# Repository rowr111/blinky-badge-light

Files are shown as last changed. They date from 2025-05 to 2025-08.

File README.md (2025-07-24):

# Blinky Badge "light"!
Hello!  Welcome to the github repo for Blinky Badge "light".

## What is this thing?
 - Blinky Badge "light" is a lighting badge with unique patterns and sound reactivity! 
 - It's meant to be worn at festivals or whenever you'd like to light your person in a fun way.  Safety!
 - Heart shaped!

## Why is it named Blinky Badge "light"?
### This project shares similar features with two projects:
   -  [bunnie's BM blinky badge of 2017 and 2020](https://github.com/bunnie/chibios-xz/tree/bm20)
   -  [the cubegarden art project](https://github.com/rowr111/cubegarden)

### So, about the name?

- Although this project was written from scratch, has some different features, and uses a different microcontroller etc from the original badge, it shares the fundamental shared goal of the original - to light up the night in a fun and personal way!
- I also re-use the pattern generation concepts from the original badge in some of the patterns, so visually there are also some similarities.
- This badge does not share the radio communication features of the original, nor does it have a screen/ui - thus it's called blinky badge "light".  (Also, it makes.. light. get it? :D)
   
## Features
### Patterns:
 - three unique patterns generated on initial startup for each badge (not sound reactive)
 - two sound reactive patterns with a base same as ^
    - flashes the whole badge
    - fills up the badge from the bottom
 - one 'safety' pattern
    - not in the normal pattern list
    - forced when battery level is very low
- future pattern ideas:
    - sound reactive pattern whose color indicates dB level?  tbd..

### Capacitive Touch Buttons:
1. iterate through unique patterns (wraps around when gets to the end)
2. change brightness level (wraps around after brightest)
3. replace current pattern with new unique pattern
    - for sound reactive patterns changes the base pattern, not sound reactivity
    - small flash on pattern change for visual indicator of change
4. off (hold)
5. check battery level
6. ? (mystery spot. does nothing for now. use it to add a feature!)

### Power Button (physical button):
 - press to turn badge on

### Power Indicator LED (small, green):
 - on during charging

## Physical Structure/Components

The badge is a heart shaped PCB with LEDs outlining the heart.  The LEDs are covered by the case for protection and some light diffusion, but the center front of the PCB is exposed for easy access of the buttons.

The form is similar to the original blinky badge, but there are differences:
 - the original has 36 LEDs, this badge has 24.
 - the original has a screen and antenna, this badge does not.
 - the original has 8 capacitive touch buttons, this badge has 3 big and 3 small ones.
 - this badge uses a user-supplied, removeable battery.

### Structural Components (WIP!)
 - PCB with these main components:
   - ESP32 microcontroller
   - microphone
   - 24 WS2812B LEDs
   - USB-C port for:
     - charging batteries
     - programming the microcontroller
   - 6 capacitive touch buttons
     - change pattern
     - change brightness
     - replace current pattern with new unique pattern
     - off
     - battery check
     - ? mystery spot
   - power button for On
   - small led for lower battery charge/currently charging indicator
   - battery holder attached to the back
      - requires one 18650 lithium-ion rechargeable battery
 - Case:
   - heart shaped ring on the front, same as the original blinky badge
   - back fully covers the back of the PCB as well as protects the battery holder
   - will have various points for attaching/hanging the badge

## How to write code for the badge!
 - Visual Studio Code
 - add the Espressif IDF extension
 - set up the extension
   - configure ESP-IDF extension, I recommend Express mode:  
     - install idf release version 5.5 (can prob use later versions too, but use at least this version)
     - no other configuration needed!
 - install CP210x Universal Windows Driver (or appropriate driver for your OS) from [CP2102N USB to UART Bridge Controller](https://www.silabs.com/software-and-tools/usb-to-uart-bridge-vcp-drivers?tab=downloads)
 - plug in badge to computer using USB-C cable that *supports data transmission*
 - open the blinky-badge-light/blinky-badge-light folder in VSCode
 - update code on badge using ESP-IDF:
   - FIRST TIME: 
     - go to ESP-IDF: EXPLORER (list of commands) from  icon in VS Code's plugin icon menu
     - select current ESP-IDF version (5.5 that you just installed)
     - select flash method - UART
     - 'Select Port to Use (COM, tty, usbserial)'
       - hold down 'ON' button on badge (or just make sure the badge is on)
       - click 'Select Port to Use (COM, tty, usbserial)'
       - pick the port that matches your badge (check in device manager if you're not sure)
     - 'Select Monitor Port to Use (COM, tty, usbserial)'
       - repeat ^ process and pick the same port
     - Full Clean
     - Build Project
     - Flash Device
       - ON button must be held down while flash happens
     - after flash is complete, release ON, then press and hold ON to start the badge
     - once badge has started, you can use 'Monitor Device' to see the serial monitor.
   - BUILDING AFTER THIS FIRST SETUP BUILD:
     - just do build/flash steps!
     - if you have problems:
       - check if the com port changed for some reason and reset them
       - full clean before rebuilding
 - Now that you know how to update the code, add your own fun stuff!
 - Code Ideas:
   - something using the antenna? 
   - cool new lighting patterns?
   - use the ? mystery spot capacitive touch pad to do something cool?

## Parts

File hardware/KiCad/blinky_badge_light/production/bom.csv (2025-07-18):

Designator | Footprint | Quantity | Value | LCSC Part #
BT1 | BatteryHolder_Keystone_1042_1x18650 | 1 | 3.7V - 4.2V | C2988620
C1, C10, C11, C12, C13, C14, C15, C16, C17, C18, C19, C2, C20, C21, C22, C23, C24, C26, C29, C3, C31, C36, C37, C38, C4, C41, C5, C6, C7, C8, C9 | 0402 | 31 | 100nF | C1525
C25, C34, C35, C40 | 0603 | 4 | 1µF | C15849
C27, C28, C39 | 0603 | 3 | 22µF | C59461
C30 | 0603 | 1 | 4.7µF | C19666
C32, C33 | 0603 | 2 | 10µF | C96446
D1, D10, D11, D12, D13, D14, D15, D16, D17, D18, D19, D2, D20, D21, D22, D23, D24, D3, D4, D5, D6, D7, D8, D9 | LED_WS2812B_PLCC4_5.0x5.0mm_P3.2mm | 24 | WS2812B | C2761795
D25 | 0805 | 1 | LED | C2297
D26 | D_SOD-323F | 1 | D_Schottky | C50704
D27 | SOT-143-4_L2.9-W1.3-P1.92-LS2.4-BL | 1 | SP0503BAHT | C3040626
D28 | D_SOD-123 | 1 | ESD Diode | C5380694
L1 | IND-SMD_L4.5-W4.1_IHLP | 1 | 4.7µH | C22463808
MK1 | InvenSense_ICS-43434-6_3.5x2.65mm | 1 | ICS-43434 | C5656610
Q1, Q3 | SOT-23-3_L2.9-W1.3-P1.90-LS2.4-BR | 2 | N-Channel MOSFET | C20917
Q2, Q4 | SOT-23 | 2 | Q_PMOS_GSD | C88052
R1 | 0603 | 1 | 100Ω | C22775
R10 | 0603 | 1 | 1kΩ | C21190
R11, R12, R13, R18, R19, R2, R20, R8 | 0603 | 8 | 10kΩ | C25804
R14 | 0603 | 1 | 3kΩ | C4211
R15, R9 | 0603 | 2 | 100kΩ | C25803
R16 | 0603 | 1 | 22.1kΩ | C25961
R17 | 0603 | 1 | 47.5kΩ | C23061
R3 | 0603 | 1 | 1Ω | C22936
R4 | 0603 | 1 | 2kΩ | C22975
R5 | 0603 | 1 | 5.1kΩ | C23186
R7 | 0603 | 1 | 73.2kΩ | C163420
SW1 | SW-SMD_4P-L5.1-W5.1-P3.70-LS6.5-TL_H1.5 | 1 | TS-1187A-B-A-B | C318884
U1 | ESP32-S3-WROOM-1 | 1 | ESP32-S3-WROOM-1 | C2913198
U2 | SOP8-PP_TPW | 1 | TP4056 | C16581
U3 | SOT-23-5 | 1 | AP2112K-3.3 | C51118
U4 | SOT-23-6 | 1 | MT3608 | C84817
U5 | QFN-24-1EP_4x4mm_P0.5mm_EP2.6x2.6mm | 1 | CP2102N-Axx-xQFN24 | C969151
U6 | SOT-23-6 | 1 | SN74LVC1T45DBV | C7843
USBC1 | USB-C_SMD-TYPE-C-31-M-12 | 1 | ~ | C165948

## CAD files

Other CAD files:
3d models/blinky_badge_light_case.f3d

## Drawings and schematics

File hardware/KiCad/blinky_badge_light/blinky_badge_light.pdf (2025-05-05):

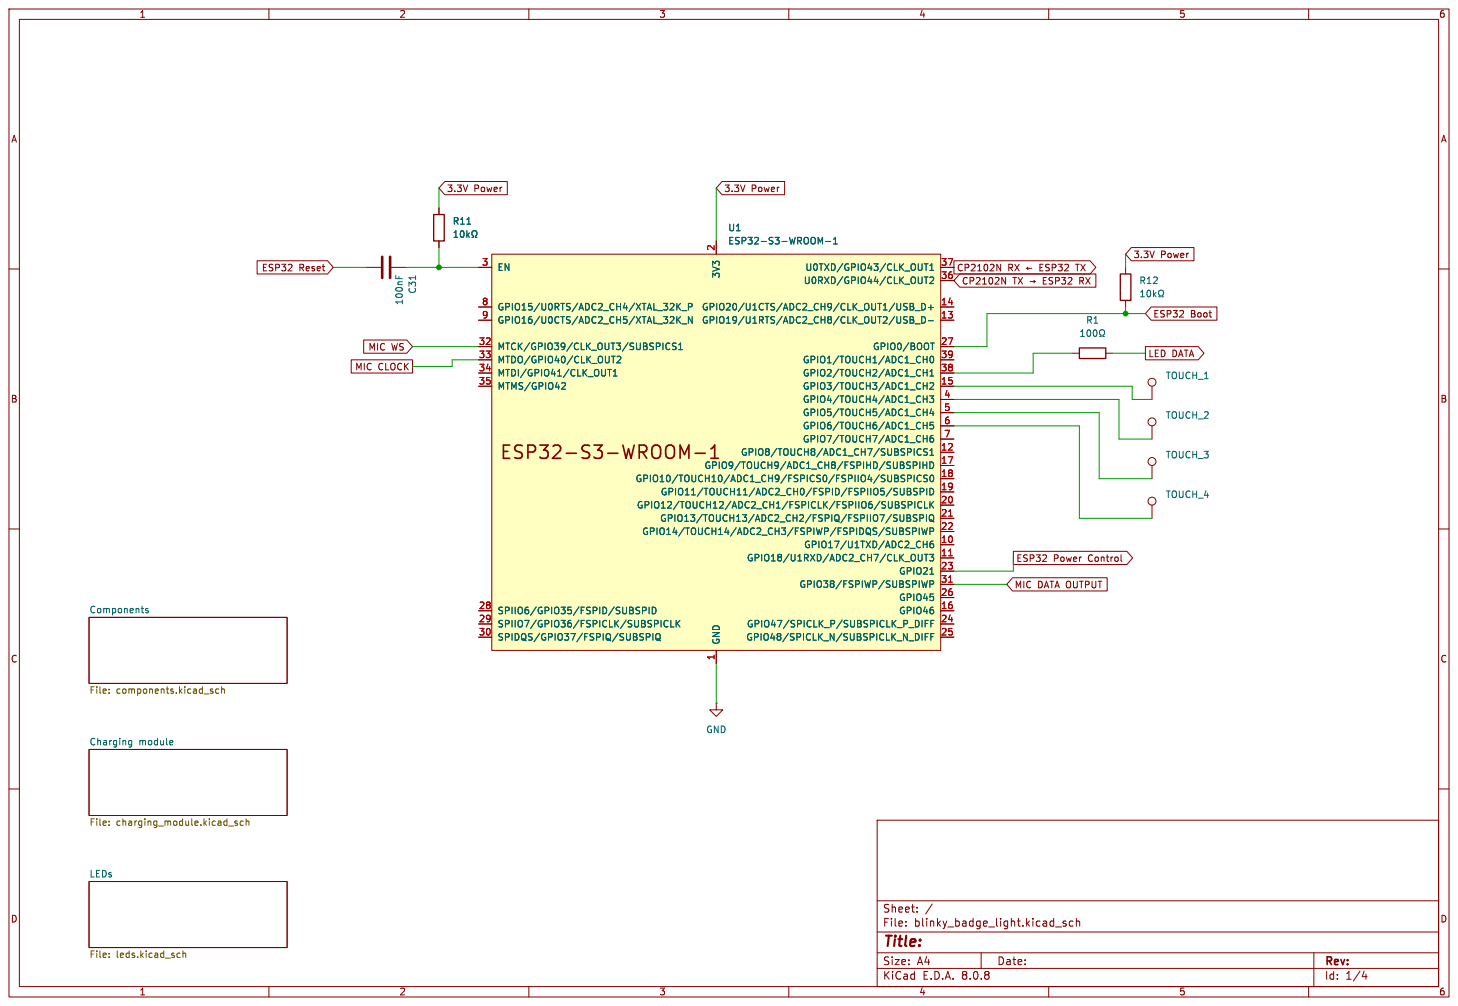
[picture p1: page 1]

2 GPIO12/TOUCH12/ADC2_CH1/FSPICLK/FSPIIO6/SUBSPICLK 20 GPIO13/TOUCH13/ADC2_CH2/FSPIQ/FSPIIO7/SUBSPIQ 21 GPIO14/TOUCH14/ADC2_CH3/FSPIWP/FSPIDQS/SUBSPIWP 22 GPIO21 23 GPIO47/SPICLK_P/SUBSPICLK_P_DIFF 24 GPIO48/SPICLK_N/SUBSPICLK_N_DIFF 25 GPIO45 26 GPIO0/BOOT 27 SPIIO6/GPIO35/FSPID/SUBSPID 28 SPIIO7/GPIO36/FSPICLK/SUBSPICLK 29 EN 3 SPIDQS/GPIO37/FSPIQ/SUBSPIQ 30 GPIO38/FSPIWP/SUBSPIWP 31 MTCK/GPIO39/CLK_OUT3/SUBSPICS1 32 MTDO/GPIO40/CLK_OUT2 33 MTDI/GPIO41/CLK_OUT1 34 MTMS/GPIO42 35 U0RXD/GPIO44/CLK_OUT2 36 U0TXD/GPIO43/CLK_OUT1 37 GPIO2/TOUCH2/ADC1_CH1 38 GPIO1/TOUCH1/ADC1_CH0 39 GPIO4/TOUCH4/ADC1_CH3 4 GPIO5/TOUCH5/ADC1_CH4 5 GPIO6/TOUCH6/ADC1_CH5 6 GPIO7/TOUCH7/ADC1_CH6 7 GPIO15/U0RTS/ADC2_CH4/XTAL_32K_P 8 GPIO16/U0CTS/ADC2_CH5/XTAL_32K_N 9 U1ESP32-S3-WROOM-1 R11

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

1 GPIO17/U1TXD/ADC2_CH6 10 GPIO18/U1RXD/ADC2_CH7/CLK_OUT3 11 GPIO8/TOUCH8/ADC1_CH7/SUBSPICS1 12 GPIO19/U1RTS/ADC2_CH8/CLK_OUT2/USB_D- 13 GPIO20/U1CTS/ADC2_CH9/CLK_OUT1/USB_D+ 14 GPIO3/TOUCH3/ADC1_CH2 15 GPIO46 16 GPIO9/TOUCH9/ADC1_CH8/FSPIHD/SUBSPIHD 17 GPIO10/TOUCH10/ADC1_CH9/FSPICS0/FSPIIO4/SUBSPICS0 18 GPIO11/TOUCH11/ADC2_CH0/FSPID/FSPIIO5/SUBSPID 19 3V3

Id: 1/4 Title: File: blinky_badge_light.kicad_sch Sheet: / LEDs File: leds.kicad_sch Components File: components.kicad_sch

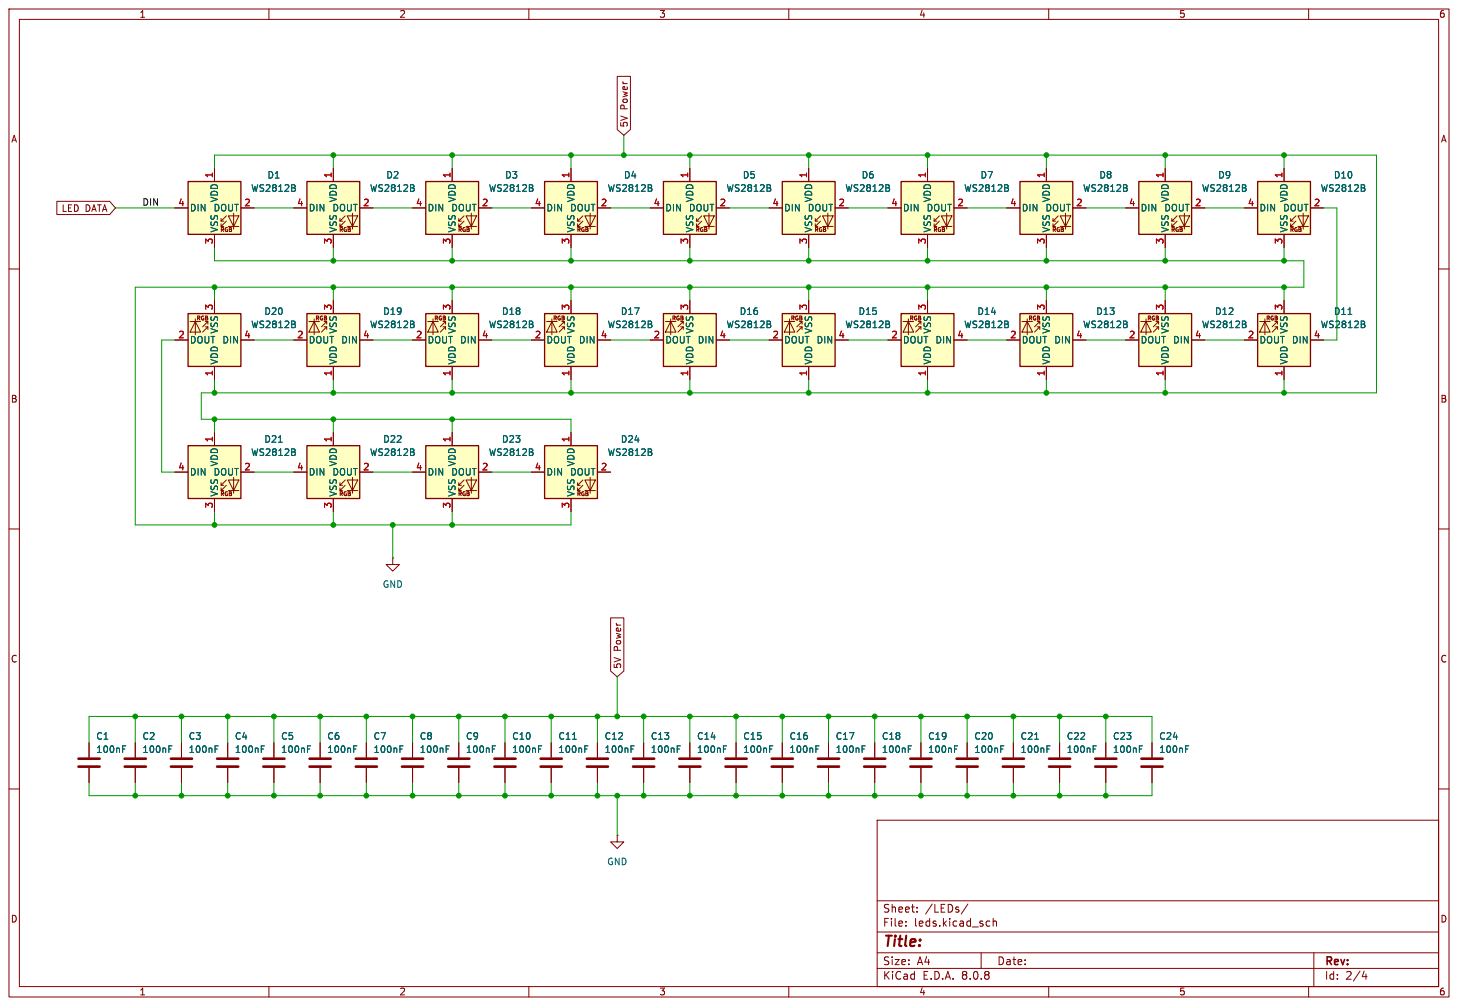
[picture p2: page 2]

Id: 2/4 Title: File: leds.kicad_sch Sheet: /LEDs/ C4

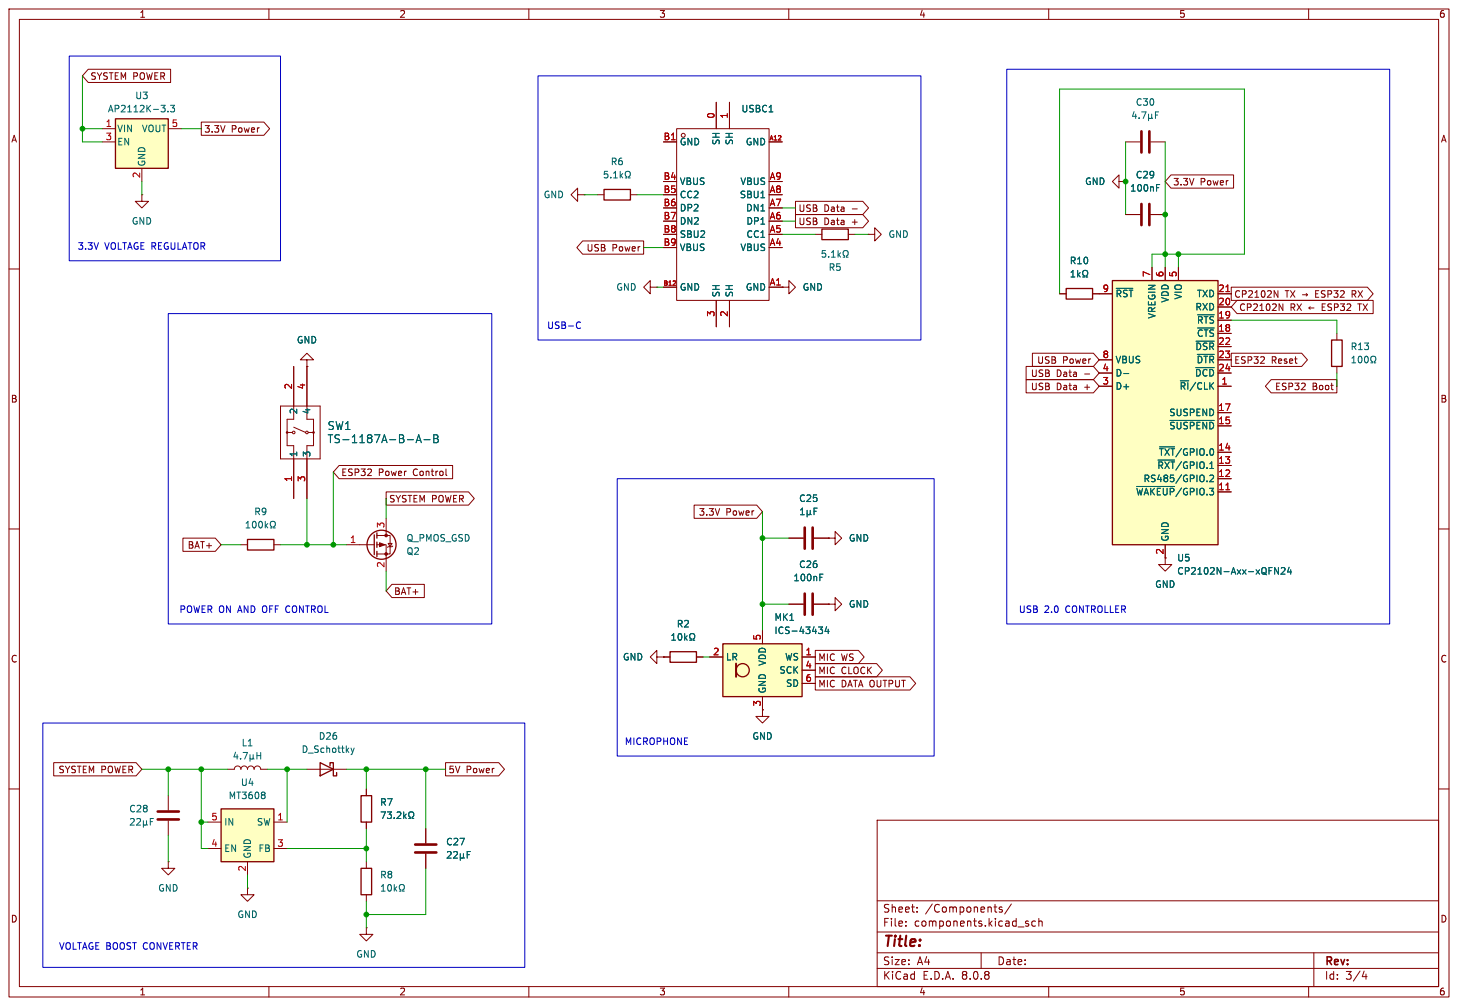
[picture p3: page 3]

2 EN 3 VOUT 5 U3 AP2112K-3.3 ~{RI}/CLK1 ~{WAKEUP}/GPIO.311 RS485/GPIO.2 12 ~{RXT}/GPIO.113 ~{TXT}/GPIO.014 ~{SUSPEND}15 SUSPEND 17 ~{CTS} 18 ~{RTS} 19 GND

3 GND A1 GND A12 VBUS A4 CC1 A5 DP1 A6 DN1 A7 SBU1 A8 VBUS A9 GND B1 GND B12 VBUS B4 CC2 B5 DP2 B6 DN2 B7 SBU2 B8 VBUS B9 USBC1 VIN 1 GND

þÿ5.1k© GND GND SH

3 GND A1 GND A12 VBUS A4 CC1 A5 DP1 A6 DN1 A7 SBU1 A8 VBUS A9 GND B1 GND B12 VBUS B4 CC2 B5 DP2 B6 DN2 B7 SBU2 B8 VBUS B9 MK1

7 VBUS 8 ~{RST} 9 U5 CP2102N-Axx-xQFN24 GND

2 RXD 20 TXD 21 ~{DSR} 22 ~{DTR} 23 ~{DCD} 24 D+ 3 D- 4 VIO

Id: 3/4 Title: File: components.kicad_sch Sheet: /Components/ C26

POWER ON AND OFF CONTROL

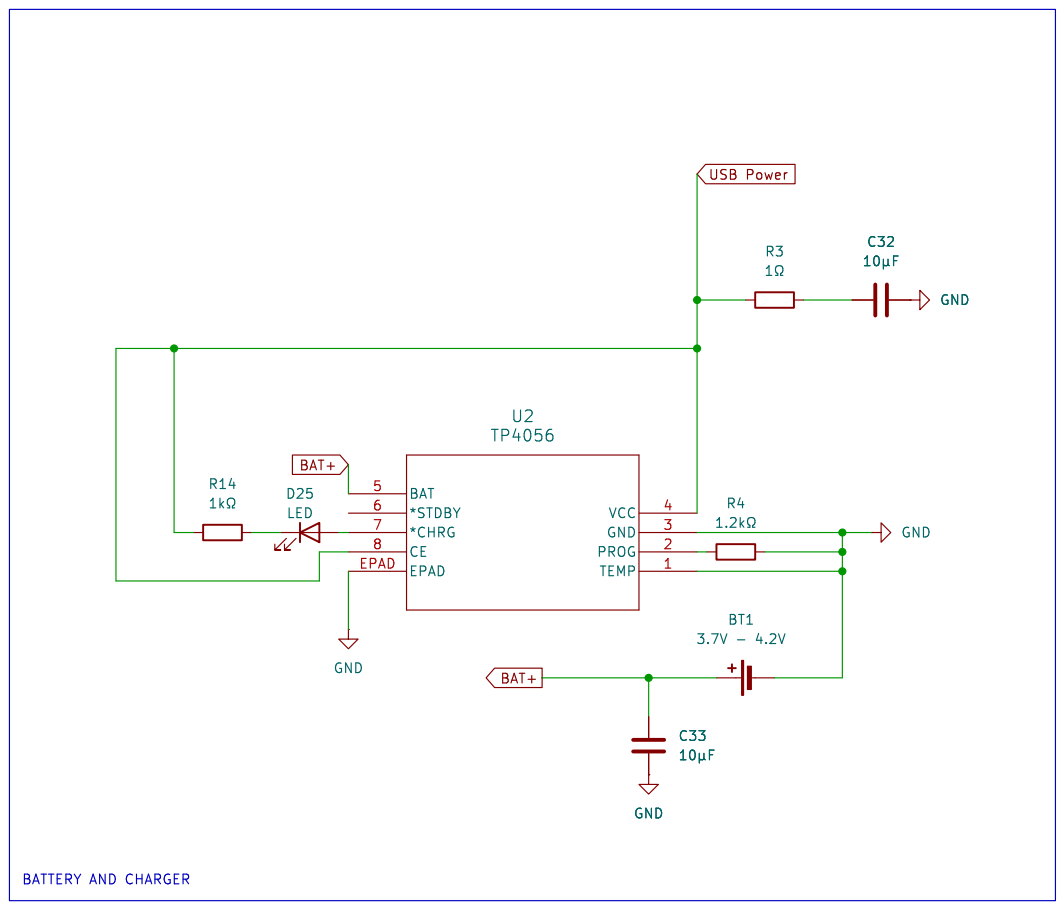
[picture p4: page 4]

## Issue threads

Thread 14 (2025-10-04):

sometimes on low battery captouch buttons don't seem to work to turn off the badge

rowr111, 2025-10-04:
maybe this is unnecessary to fix if I switch to using the same push button button for off/on.  I couldn't repro it here no matter what I tried but I did see it in the field.  could try recalibrating captouch buttons when reach low voltage.

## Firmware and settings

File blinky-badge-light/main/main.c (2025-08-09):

#include "esp_log.h"
#include "esp_timer.h"
#include "freertos/FreeRTOS.h"
#include "freertos/task.h"
#include "nvs_flash.h"
#include "esp_system.h"

#include "battery_monitor.h"
#include "battery_level_pattern.h"
#include "led_control.h"
#include "touch_input.h"
#include "storage.h"
#include "genes.h"
#include "pins.h"
#include "microphone.h"
#include "now.h"
#include "testing_routine.h"

void app_main() {
    esp_reset_reason_t reason = esp_reset_reason();
    ESP_LOGI("MAIN", "Reset reason: %s", reset_reason_str(reason));

    // Initialize NVS
    esp_err_t ret = nvs_flash_init();
    if (ret != ESP_OK) {
        ESP_ERROR_CHECK(nvs_flash_erase());
        ret = nvs_flash_init();
    }
    ESP_ERROR_CHECK(ret);

    // Load or generate genomes
    load_genomes_from_storage();
    // Initialize components
    init_leds();
    init_touch();
    init_microphone();
    now_init();
    init_storage();
    init_battery_monitor();

    load_settings(&settings);
    set_pattern(settings.pattern_id);
    set_brightness(settings.brightness);

    ESP_LOGI("MAIN", "System initialized. Starting tasks...");

    // Create tasks
    xTaskCreatePinnedToCore(lighting_task, "Lighting Task", 4096, NULL, 5, NULL, 1);
    xTaskCreatePinnedToCore(battery_monitor_task, "Battery Monitor Task", 4096, NULL, 5, NULL, 0);
    xTaskCreatePinnedToCore(microphone_task, "Microphone Task", 4096, NULL, 5, NULL, 0);
    xTaskCreatePinnedToCore(touch_task, "Touch Task", 4096, NULL, 5, NULL, 0);
}

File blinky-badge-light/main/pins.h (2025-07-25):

#ifndef PINS_H
#define PINS_H

#include <driver/gpio.h>

// LED pins
#define LED_PIN GPIO_NUM_2 // GPIO pin for LED data
#define LED_COUNT 24 // Number of LEDs

// Battery monitoring pins
#define ADC_CHANNEL ADC_CHANNEL_8   // GPIO9 on ADC1
#define ADC_GPIO    GPIO_NUM_17
#define BATTERY_MONITOR_ENABLE_PIN GPIO_NUM_46 // GPIO46 controls battery monitor transistor

// Power pins
#define MOSFET_GATE_PIN GPIO_NUM_21
#define BUTTON_PIN 27 // Power button

// Microphone pins
#define I2S_SCK_PIN GPIO_NUM_40  // Clock Pin (BCLK), pin 33
#define I2S_WS_PIN  GPIO_NUM_39  // Word Select (LRCLK), pin 32
#define I2S_DI_PIN  GPIO_NUM_38  // Data In (DOUT), pin 31

#endif // PINS_H

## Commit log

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2024-12-31 fixing the touch input
    [main.c]
2025-01-01 generate new genome on long press of button 2, clean up press detection code
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2025-01-02 safety dance! we can dance if we wannuuuu... (even when power is critically low lol) - adding safety pattern.
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2025-02-09 first pass at hardware schematic
    [blinky_badge_light.kicad_pcb, blinky_badge_light.kicad_sch, charging_module.kicad_sch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]
2025-05-05 updates to hardware schematic
    [blinky_badge_light.kicad_pcb, blinky_badge_light.kicad_sch, charging_module.kicad_sch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]
2025-05-07 hardware updates, gitignore to ignore backups
    [blinky_badge_light.kicad_pcb, blinky_badge_light.kicad_sch]
2025-05-09 stuff from today
    [blinky_badge_light.kicad_pcb, blinky_badge_light.kicad_sch, charging_module.kicad_sch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]
2025-05-09 small changes from today
    [blinky_badge_light.kicad_pcb]
2025-05-09 changing led locations
    [blinky_badge_light.kicad_pcb]
2025-05-10 placing items on the board
    [blinky_badge_light.kicad_pcb, components.kicad_sch, leds.kicad_sch]
2025-05-12 fix some stuff with the footprints, rearrange some things
    [blinky_badge_light.kicad_pcb, blinky_badge_light.kicad_sch, components.kicad_sch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]
2025-05-13 pad 4 is now stop sign shaped since its the off button
    [blinky_badge_light.kicad_pcb, blinky_badge_light.kicad_sch]
2025-05-16 add exclusion zone for pads/screw holes for fill area
    [blinky_badge_light.kicad_pcb]
2025-05-17 some initial slight mods
    - improved USB signal layout
    - reviewed boost regulator
    - improved 3.3V power layout
    still need to have a look at the overall USB power routing
    [blinky_badge_light.kicad_pcb]
2025-05-17 rotate battery, charger IC
    [blinky_badge_light.kicad_pcb]
2025-05-18 clean up labels on the back
    [blinky_badge_light.kicad_pcb, blinky_badge_light.kicad_sch]
2025-05-19 update with routing
    [blinky_badge_light.kicad_pcb, blinky_badge_light.kicad_sch]
2025-05-20 revert last changes so I can merge other branch in
    [blinky_badge_light.kicad_pcb, blinky_badge_light.kicad_sch]
2025-05-20 clean up labels
    [blinky_badge_light.kicad_pcb]
2025-05-20 finish routing and clean up based on DRC
    [blinky_badge_light.kicad_pcb]
2025-05-21 drew some stuff for the pads and off/on
    [blinky_badge_light.kicad_pcb]
2025-05-23 updated schematic to use 'basic' parts from jlcpcb where I could
    [blinky_badge_light.kicad_pcb, blinky_badge_light.kicad_sch, charging_module.kicad_sch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]
2025-05-23 put my name on it
    [blinky_badge_light.kicad_pcb]
2025-05-24 swap out inductor
    [blinky_badge_light.kicad_pcb, components.kicad_sch]
2025-05-26 mysterious items that changed when I was exporting things
    [blinky_badge_light.kicad_pcb]
2025-06-05 this is a hot mess, but this loads on the board.. committing to save progress
2025-06-06 fixing more exciting things (touch pads working!)
    [battery_monitor.c, battery_monitor.h, main.c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]
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2025-06-09 fix datasheet for inductor
    [components.kicad_sch]
2025-06-09 swap esp32 boot and reset's connections to CP2102
    [blinky_badge_light.kicad_pcb, blinky_badge_light.kicad_sch]
2025-06-09 charging led is too bright, swapped resistor from 1k to 3k
    [blinky_badge_light.kicad_pcb, charging_module.kicad_sch]
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2025-06-10 use new label footprints, also move and adjust routing for off and on
    [blinky_badge_light.kicad_pcb]
2025-06-10 don't silkscreen outline around leds on the front
    [blinky_badge_light.kicad_pcb]
2025-06-11 adding plus and minus to inside battery holder so it's easier to see which direction to use
    [blinky_badge_light.kicad_pcb]
2025-06-11 added battery polarity protection and charging monitoring circuit
    [blinky_badge_light.kicad_sch, charging_module.kicad_sch]
2025-06-14 fix symbol used by transistor
    [blinky_badge_light.kicad_pcb, charging_module.kicad_sch]
2025-06-14 moving some stuff around
    [blinky_badge_light.kicad_pcb, blinky_badge_light.kicad_sch]
2025-06-15 adding two new touch pads
    [blinky_badge_light.kicad_pcb, blinky_badge_light.kicad_sch]
2025-06-15 new labels, new pads
    [blinky_badge_light.kicad_pcb]
2025-06-15 hanger ring
    [blinky_badge_light.kicad_pcb]
2025-06-16 adding a bunch of qs and annotated items on schematic
    [blinky_badge_light.kicad_pcb, blinky_badge_light.kicad_sch, charging_module.kicad_sch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]
2025-06-17 review feedabck
    [blinky_badge_light.kicad_pcb, bom.csv, charging_module.kicad_sch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]
2025-06-17 change reverse battery protection circuit so diode goes to ground
    [blinky_badge_light.kicad_pcb, charging_module.kicad_sch]
2025-06-17 update battery protection circuit and draw routes
    [blinky_badge_light.kicad_pcb, charging_module.kicad_sch]
2025-06-18 remove text from review
    [blinky_badge_light.kicad_sch, charging_module.kicad_sch, components.kicad_sch]
2025-06-18 fixing a couple things and exported files
    [blinky_badge_light.kicad_pcb, bom.csv, charging_module.kicad_sch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]
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2025-06-29 adding case fusion 360 archive
    [blinky_badge_light_case.f3d]
2025-06-30 make tasks stop interfering with the lighting task! also some cleanup etc
    [battery_monitor.c, main.c, pins.h]
2025-07-01 added new transistor and resistor to battery monitoring circuit, adjusted two leds/capacitors position slightly
    [blinky_badge_light.kicad_pcb, charging_module.kicad_sch]
2025-07-01 changed resistors on battery monitoring (back) to 10k
    [blinky_badge_light.kicad_pcb, charging_module.kicad_sch]
2025-07-03 production files for v3
    [bom.csv, designators.csv, positions.csv]
2025-07-04 messy but effective (?) fix for stuck pads (can happen when multiple pads held down at once)
    [main.c]
2025-07-05 change charging prog resistor to 2k to keep things cooler
    [blinky_badge_light.kicad_pcb, charging_module.kicad_sch]
2025-07-10 slight adjusting of led positions to make things fit more nicely under the front cover
    [blinky_badge_light.kicad_pcb]
2025-07-11 battery level pattern should only fall off an led at the end of its range
2025-07-14 save initial settings after trying to load and initially not finding any so that it can load them on subsequent power ups
2025-07-14 battery monitoring has some problem running the task the first time, logging during init helps for some reason. also 3x check before shutoff
    [battery_monitor.c]
2025-07-17 remove comment from schematic
    [charging_module.kicad_sch]
2025-07-17 put wait at the beginning of the battery task to give it a little time after it starts up to settle down
2025-07-18 board v4
    [bom.csv, positions.csv]
2025-07-18 testing routine now available on startup. also print out reset reason at start
    [battery_monitor.c, main.c]
2025-07-19 add short leds off in mic test before final result display
2025-07-21 dont need name, better debugging printout when generating pattern, better pattern when full rainbow
2025-07-25 fix small bug in battery monitoring code
    [battery_monitor.c]
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2025-08-09 fix testing routine - now requires all three main pads to be held for 2 sec
    [battery_monitor.c, main.c]
